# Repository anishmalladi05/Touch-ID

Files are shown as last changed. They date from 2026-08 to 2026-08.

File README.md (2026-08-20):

# Touch-ID
A 1 key macropad. Macbooks don't allow for touch ID on external keyboards, so I will make a 1 key macropad  that just types out my password. PCB will be made in KiCAD, code is VS code, and case in Fusion 360.

## Assembly:
Take the pcb and use the through hole components to solder the seeeduino and the switch
<br></br>
Use double sided tape (if wanted) to secure the pcb to the bottom case
<br></br>
Take the top part of the case and screw it in
<br></br>
Put the keycap on
<br></br>

## Flashing:
To flash the firmware, press the bott button and while holding it press the reset button
<br></br>
You should see a drive called RP1-RP2
<br></br>
Drag the uf2 file into the drive
<br></br>
Now you should see a drive called CIRCUITPY
<br></br>
Delete everything in there and replace it with everything in the code folder so it looks like this:
Screenshot 2026-08-20 at 4 50 57 PM

## Updating Code:
Update the code in the place where it says YOURPASSWORD, replace it with your actual password

## Images:
Screenshot 2026-08-20 at 4 15 45 PM
Screenshot 2026-08-20 at 4 32 59 PM

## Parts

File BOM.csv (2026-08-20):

Item | "Link" | "Price"
1x MX CHERRY SWITCES: | https://www.amazon.com/CHERRY-Switch-Mechanical-Keyboard-Switches/dp/B0FYR9X5QH?sp_csd=d2lkZ2V0TmFtZT1zcF9hdGY | "$15"
1x Keycaps (Can buy own, or 3d print files are in the CAD folder): | https://www.amazon.com/Elacgap-Profile-switches-Mechanical-Keyboard/dp/B0CQ2Y15Y5 | "$12"
1x SEEEDUINO XIAO RP2040: | https://www.seeedstudio.com/Seeed-Studio-XIAO-ESP32S3-Pre-Soldered-p-6334.html | "$4"
1x Ability to solder: | Please provide yourself | "Free!"
1x PCB (found in PCB files): | jlcpcb.com | "$4"
1x UCB-C cable to connect to device: | https://www.amazon.com/Amazon-Basics-Charger-480Mbps-Certified/dp/B01GGKZ2SC?sp_csd=d2lkZ2V0TmFtZT1zcF9hdGY | "$10"
1x Coding skills (only if you want to customize): | Please provide yourself | "Free again!"
1x 3D printer with 1 spool filament: | https://us.store.bambulab.com/products/a1-mini?from=navigation | "$220"
2x Socket head cap screws SHCS.M316-50: | https://www.mcmaster.com/products/cap-screws/fastener-head-type~socket/?matchtype=p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 | "$5"

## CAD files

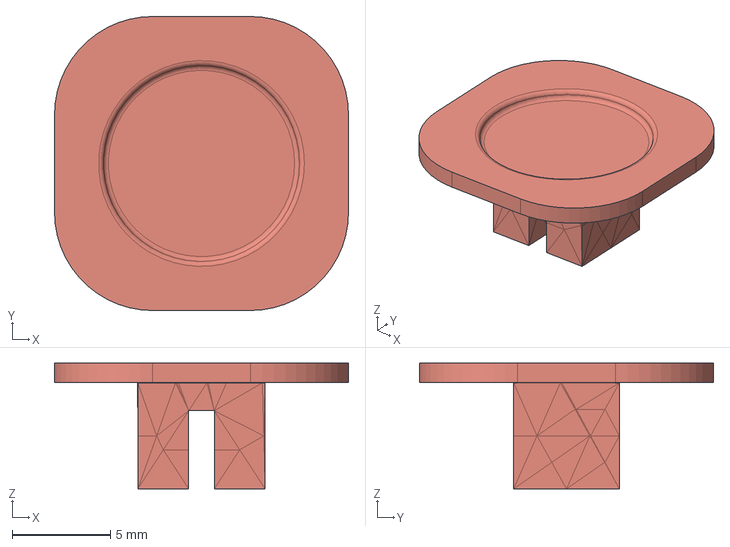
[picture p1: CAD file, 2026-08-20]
CAD/Touch ID Screw keycap.step
15.0 x 15.0 x 6.41 mm

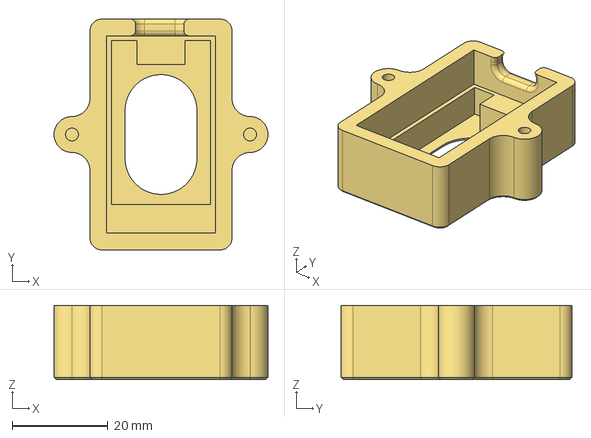
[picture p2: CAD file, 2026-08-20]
CAD/Touch ID Screw bottom.step
44.6 x 48.2 x 15.5 mm

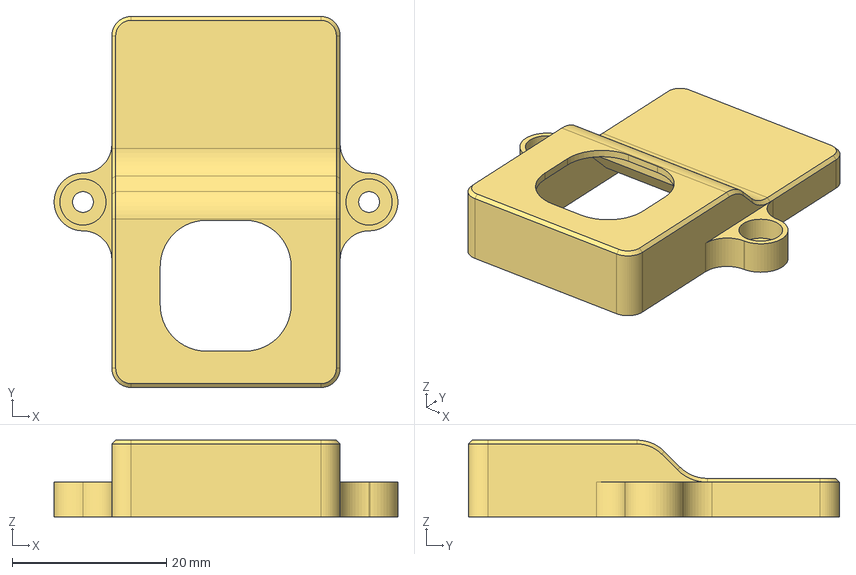
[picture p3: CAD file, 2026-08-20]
CAD/Touch ID Screwtop.step
44.6 x 48.2 x 9.97 mm

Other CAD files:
CAD/Touch ID Screw bottom.stl
CAD/Touch ID Screw keycap.stl
CAD/Touch ID Screwtop.stl

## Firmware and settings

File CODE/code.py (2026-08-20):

import time
import board
import digitalio
import usb_hid
from adafruit_hid.keyboard import Keyboard
from adafruit_hid.keyboard_layout_us import KeyboardLayoutUS
from adafruit_hid.keycode import Keycode

keyboard = Keyboard(usb_hid.devices)
layout = KeyboardLayoutUS(keyboard)

# Set up Pin 3 (D3) as custom ground
custom_ground = digitalio.DigitalInOut(board.D3)
custom_ground.direction = digitalio.Direction.OUTPUT
custom_ground.value = False

# Set up Pin 0 (D0) as input switch
switch = digitalio.DigitalInOut(board.D0)
switch.direction = digitalio.Direction.INPUT
switch.pull = digitalio.Pull.UP

print("Ready!")

while True:
    if not switch.value:
        layout.write("YOURPASSWORD")
        keyboard.send(Keycode.ENTER)
        
        # Wait until released
        while not switch.value:
            time.sleep(0.01)
            
        time.sleep(0.2)
        
    time.sleep(0.01)

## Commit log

2026-08-20 Rename Touch ID Screwtop.step to PCB/Touch ID Screwtop.step
    [Touch ID Screwtop.step]
2026-08-20 Rename Touch ID Screwtop.step to CAD/Touch ID Screwtop.step
    [Touch ID Screwtop.step]
2026-08-20 added cad
    [Touch ID Screw bottom.step, Touch ID Screw bottom.stl, Touch ID Screw keycap.step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]
